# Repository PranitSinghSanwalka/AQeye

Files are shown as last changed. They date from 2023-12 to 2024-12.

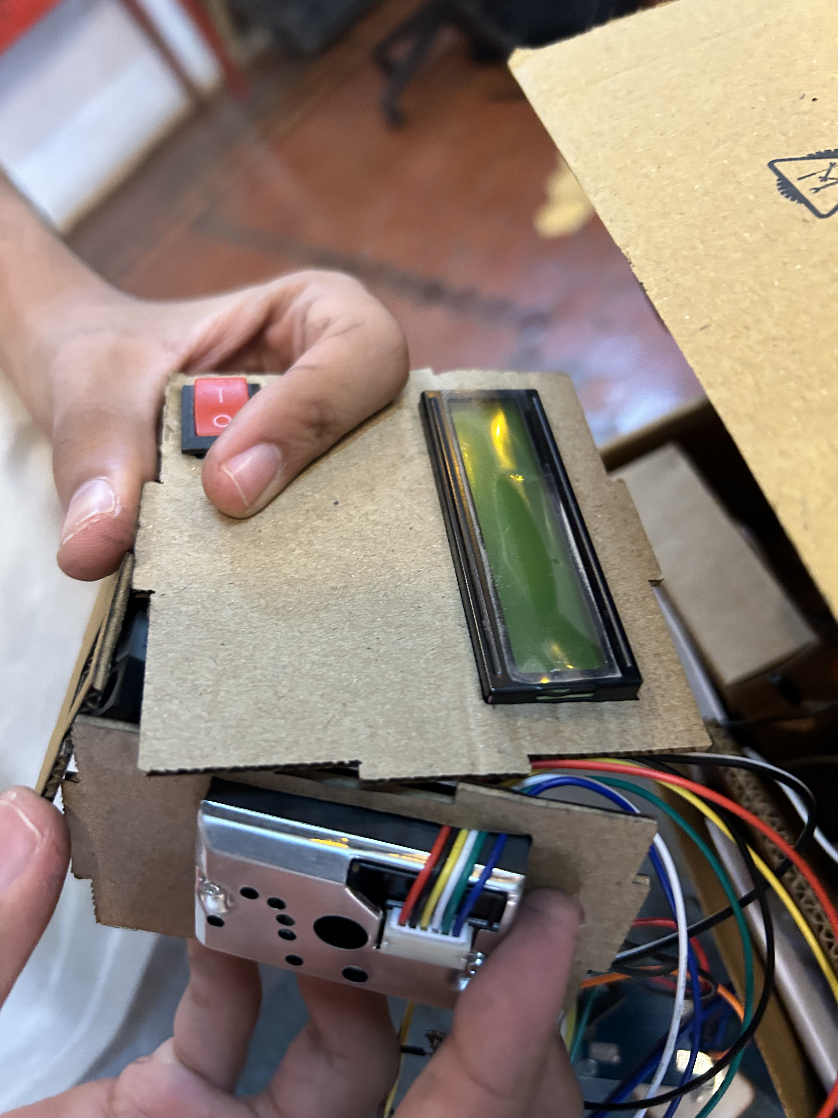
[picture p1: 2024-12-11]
FirstPrototype/Photos and Videos First Prototype/Full packaging paper prototype 2.jpeg

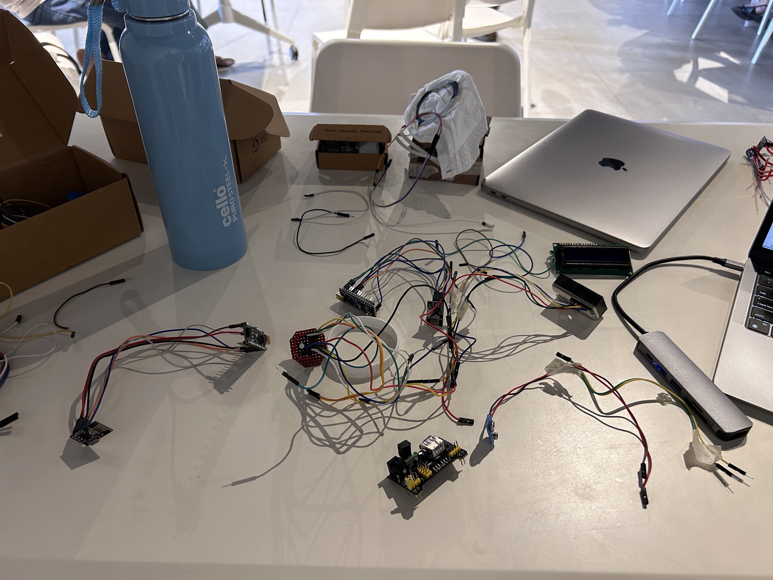
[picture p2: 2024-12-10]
Second Prototype/Second Prototype Photos and Videos/Testing_components_3.jpeg

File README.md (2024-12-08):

# AQeye
The AQeye Project by Pranit Sanwalka 

The goals:
Raise awareness about the growing air quality issues in growing cities, and try and get more people to wear masks to protect their bodies from harmful particles and air pollution

The Project:
A Mask that glows and changes colour, reacting to the air quality in real time via inbuilt air quality sensors, which also streans air quality data straight to your phone, so that you and those around you always know the air quality, and can take measures to protect themselves.

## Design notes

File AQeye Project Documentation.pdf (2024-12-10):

### AQeye

Problems:
1. Cities around the world, and especially in India, are getting increasingly polluted which poses a serious health risk
2. People in many of these cities, especially in Indian cities, are not aware of the need to wear masks to protect themselves from the pollution
3. People do not enjoy wearing masks, and do not know when they need to wear a mask and when not to, so they avoid wearing masks

Aims of Product
AQeye is a product aimed to increase awareness about the need to wear masks, and to give its users accurate on location data of the air quality in their immediate atmosphere, so that they know whether they need to wear a mask or not

Product:

AQeye is a mask that lights up and changes colour [LED’s change colour] depending on the air quality around you. This aims to send a message to those around you to wear a mask, through the use of stark colours.

AQeye also has sensors including a Dust Sensor, capable of measuring particles up to 0.3 microns small (smaller than PM2.5), and a CO2 gas sensor. It sends live data recorded from these sensors to your phone for you to check, and can alert you when you need to wear a mask based on this data.

Inspiration for product:
I had personally lived in the Delhi NCR region, one of the most polluted areas, for 4 years, and frequently visited it even during the highly polluted Diwalli and Winter times. While walking outside the Delhi airport, I nearly collapsed and fainted as I realised that I was unable to breathe, and couldnt walk for a long time, causing me to almost miss my flight. This incident made me wonder whether I could have protected my lungs and myself by wearing a mask in that situation, and made me wonder why I, and those around me, did not wear a mask. Thus I came up with AQeye to solve this.

The name AQeye is a spinoff of the term AQI (Air Quality Index) and was named with the idea that it allows the users to keep an “eye” on the Air Quality around them.

How it works:

The Product consists of two parts: The LED strip on the mask (The mask can be any disposable N95 mask and can be easily interchanged without needing a new LED system), and the main hub

First Prototype:

This prototype had the Dust Sensor, electronics and the batteries in a box shaped hub which could be attached to a backpack or other wearable via clips. This was connected to the LED’s on the mask by wire.

In the First prototype, I also attempted to collect Air Quality data from an online API with the help of a GPS sensor which returned latitude and longitude data, which the API took as an input to return data.

a. The idea was that the user would carry a small hub containing the main heavier or bulkier electronics and sensors, that could be attached to a pocket, bag or strapped to an arm or otherwise, and would allow the user to wear a mask wirelessly without the trouble of having an uncomfortable mask, as masks are already not favoured by many.
While intended to be wireless, with code and hardware already ready, we ran out of time and were unable to get the particular nRF24l01 transceivers to recognise each other, and there were no other transceivers immediately available.
i. Hub:
1. This is where the main electronics and sensors are stored
2. It should ideally be as small as possible, with the current electronics could possibly be reduced to the size of an uno card pack (maximum) Note: Currently it is much bigger as I have not used a single pcb board for the electronics, and most of the space is taken up by wiring, as the final prototype was assembled last minute without time to shorten connections, and readymade jumper cables were used.

### 3. It contains an esp wifi board, 7 pin LCD display (with I2C interface), A

breadboard power board, 2 9v batteries (one for the board, one for the other electronics, though with the right wiring one is enough), a dust sensor (Compact Optical Dust Particle Sensor GP2Y1010AU0F) (can sense down to pm2.5)
4. It was also intended to contain a GPS module and a radio transceiver module*
5. Current functionality: Senses the dust particle density in the air, and depending on this, controls the LED ring on the mask via cables. It also displays this data on a screen.
6. Intended functionality (could not be achieved, due to time constraints): Aside from the dust sensor, the esp would also use data from an API which returns AQI values from the nearest meteorological data center, as fitting an “AQI” sensor is unrealistic, as it depends on too many factors, while dust and particulate matter not only is damaging, but varies more from place to place, and can be filtered out by an n95/n99 mask (most).
The board would thus use this data to calculate the colour the mask should reflect, and then using the transceiver sends data to the mask
ii. Mask:
1. A disposable n95 mask (for the project the disposable 3M Vflex mask was used due to its spilloff areas on the sides, which provided more space to mount electronics if needed (though not used), and has a flat bottom, so an led ring can be easily stuck

2. This mask currently has an led ring that is attached to the mask (Was intended to be an LED strip, but a ring consumes less power and proved to be more reliable and easier to interface)
3. It was intended to have an arduino nano (or smaller board) attached to a transceiver and then this LED ring, allowing for wireless transmission between the hub and mask to ensure the mask is as light as possible.
2. Planned features (Aside from some of the main intended features of the first prototype mentioned above)
a. A notification feature that notifies users on their phone when the air quality of a certain area that they are in exceeds a certain amount
b. A “forecast” feature that would allow users to tell whether they need to take their mask in the morning, by checking the color it is glowing
The idea behind this was that many people hang their masks on their front door or near their exit (used to during covid) for easy access, and this could provide a visual aide as to whether the air quality outside (according to API data) is good or bad, like a rain forecast
c. A map integrated feature that allows you to look at places that you visited and their corresponding air quality near you (from recorded data when you visited, to help you plan ahead.
3. Some other constraints:
a. The api feature would need a permanently on hotspot, which may not be ideal, but could work for the home forecast feature
b. Scaling down the hub and making it more robust and user friendly is always an issue

Problems faced:

Initially, a wireless connection was planned between the LED’s on the mask and the main hub using NRF24L01 Radio transceivers, and an additional arduino board and battery separately on the mask to allow this, however a connection could not be reliably established, after several tries and different boards.

Additionally, the hub was large and difficult to carry around, even though most of the volume inside the hub was occupied by jumper cables that could be eliminated via the use of a PCB.

There was also the safety concern of having batteries on the users face if a wireless connection was to be used, which was not ideal.

Finally, an LED ring was used instead of an LED strip as the LED strips that had been purchased stopped working, and due to the time constraints of the Maker’s Asylum Innovation School Program where this was developed, an LED ring that was immediately available was used as an alternative.

More information on the first prototype can be found here:

The second prototype:

Video (Presenting working prototype at Make, Break, Create Summit, Museum of Solutions, Mumbai in partnership with the UNDP): https://www.instagram.com/reel/C6Vq0jooUJX/?utm_source=ig_web_button_share_sheet&igsh=MzRlODBiNWFlZA== (https://www.instagram.com/reel/C6Vq0jooUJX/?igsh=MzRlODBiNWFlZA==)

To create a disposable n95 mask attachment that reacts to the air quality around it in real-time, and reflects it by glowing different colors. Real-time data of air pollution measurements/values in their immediate environment also need to be sent to the user's phone so that they know when to wear a mask and when they are safe or not

The second prototype built on the first, but abandoned the wireless transmission due to the lack of reliability and safety concerns of batteries on the face.

Description:
The second AQeye prototype consists of a mask with an LED strip, similar to the one in the first prototype, which is connected by a short wire to a neckband which the user can wear around their neck comfortably. This runs on rechargeable battery power. It boasts a Dust Sensor and a gas sensor capable of detecting CO2 concentrations, with Data sent directly to the user's phone.

The mask displays 3 colours: Green (Good), Yellow (Poor) and Red (Extremely Injurius).

Design of the second prototype:

The hub was also redesigned to become a neckband, which connects to the LED’s on the mask via a short wire, which increases the comfort of carrying it around, and also allows the mask and hub to become one unit. A neckband may also be more socially acceptable due to the wide variety of electronics filled neckbands on the market, such as those with bluetooth earphones and the Bose Soundwear Companion Wireless Wearable Speaker, which inspired the product's design.

The screen to display the air quality, which was included in the initial prototype, was abandoned as a screen would not be easy to view on a neckband, and sending data to a phone not only saves space, but also allows more information to be displayed due to a larger screen. It also reduces the volume and weight.

Finally, the Air Quality API that was planned to be used in the first prototype was abandoned, as later it came to light that it would not be as useful as having on location data. Additionally the API data is offered to everyone directly on their phones, therefore the AQeye mask would not be helping the user much by giving them data they already had access to.

Problems Faced:
- The second prototype's neckband design was rushed, resulting in a large bulky neckband with open spaces to allow modification of the electronics due to time constraints.
- Additionally, Wifi was used as a means to transmit data from the neckband to the user’s phone [Blynk App] as this was the easiest and fastest way to achieve this goal in the short time period of the Maker’s Asylum SDG Acceleration Program where it was improved upon. In a future model, bluetooth will be used for transmission. However a custom app will have to be created.
- (The ESP32 board used has built in BT capabilities)
- A latch system needs to be designed for the LED’s on the mask so that the mask can be easily changed
- A higher capacity battery probably needs to be used, and an operating voltage optimal for all components set, preferably without a buck converter as it consumes a lot of power.
- Finally, the product has to be made more aesthetically pleasing, comfortable, compact and lightweight so that it appeals to users. This can be achieved to some extent through:
- Using a singular custom Flex PCB shaped to the neckband’s size. This will make it more compact and robust
- The neckband itself can be 3d printed and be fully enclosed to make it more aesthetically pleasing, compact and comfortable

Components used:

- 1x ESP32 (Main Board)
- 1x Lm2596 DC Buck Converter Step Down Power Module
- 2x 3.3V 600mAh LiPo Batteries (Wired in series to give 7.6V to the buck converter)
- 1x WS2812B LED Strip (12 LED’s) / NeoPixel LED Strip
- 1x Sharp GP2Y1010AU0F Optical Dust Sensor
- 1x MQ-135 Gas Sensor

Ideas for improvements:
a. A notification feature that notifies users on their phone when the air quality of a certain area they are in exceeds a certain amount
b. A “forecast” feature that would allow users to tell whether they need to take their mask in the morning, by checking the color it is glowing
The idea behind this was that many people hang their masks on their front door or near their exit (used during COVID) for easy access, and this could provide a visual aide as to whether the air quality outside (according to API data) is good or bad, like a rain forecast
c. A map-integrated feature that allows you to look at places that you visited and their corresponding air quality near you (from recorded data when you visited, to help you plan.

Sketches, diagrams and images of the prototypes:

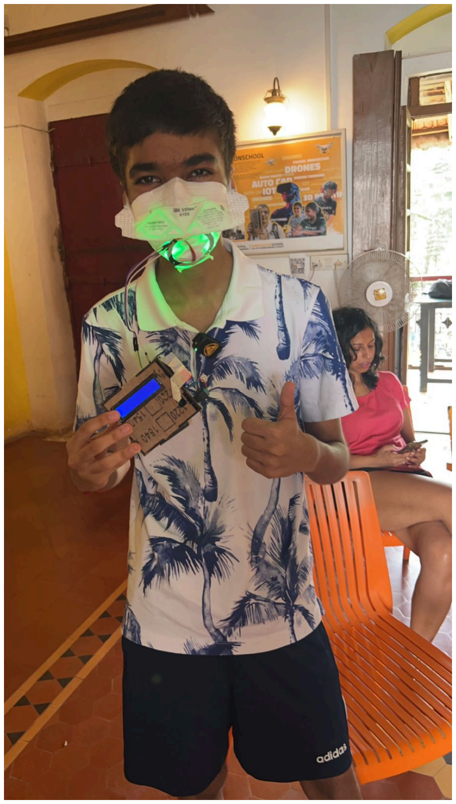
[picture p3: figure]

Picture of the first prototype (Extremely rough version, led ring not properly attached, hub made out of thin plywood hot glued together and batteries taped on.)

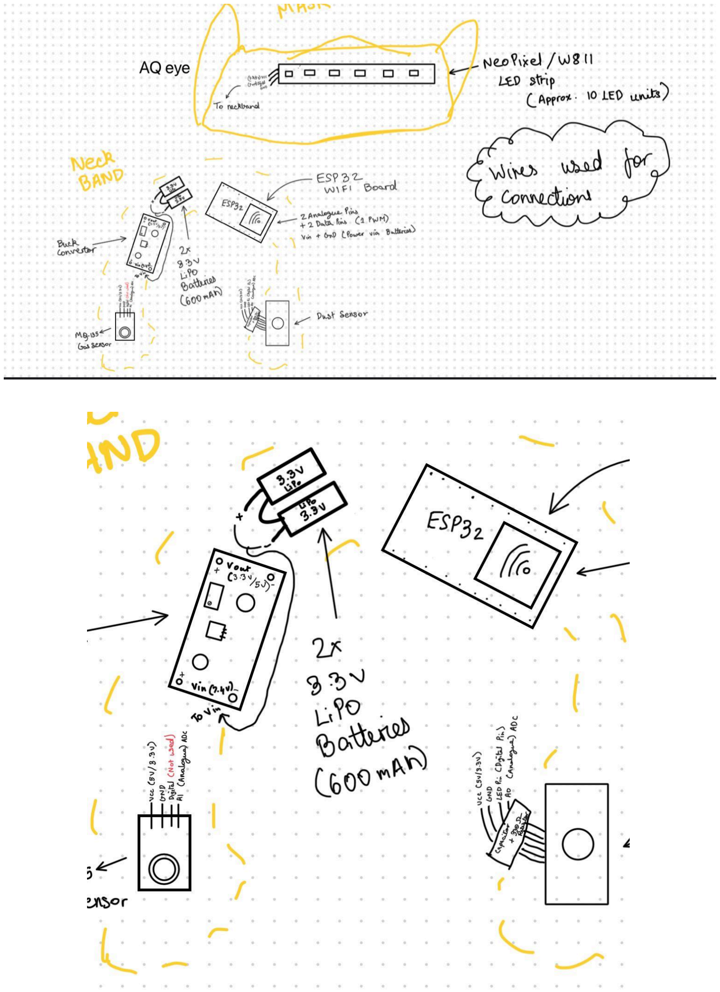
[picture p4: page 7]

Note: the voltage requirements of the ESP32 (3.3V) is lower than the operating voltage of the sensors (5V) and LEDs which was not accounted for.

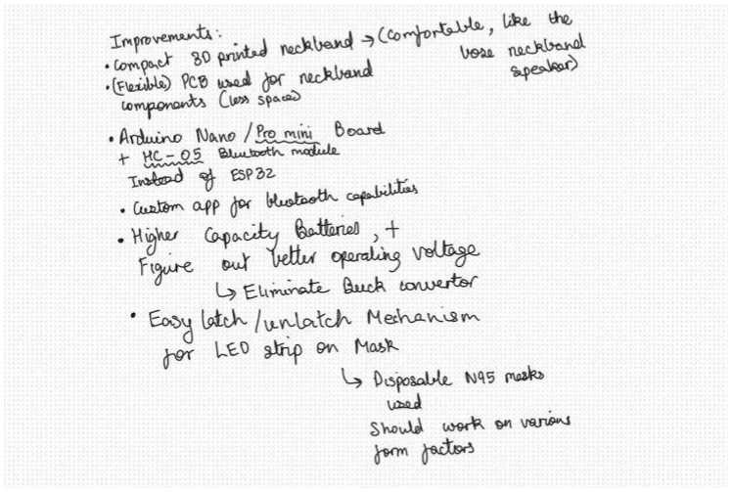
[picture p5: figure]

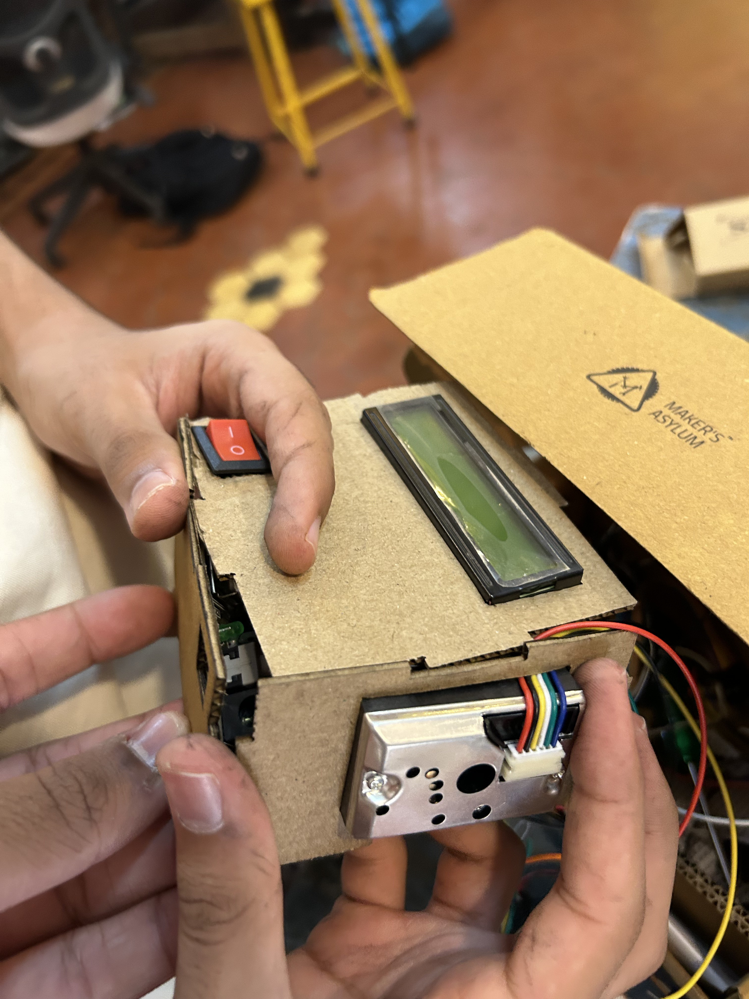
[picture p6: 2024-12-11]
FirstPrototype/Photos and Videos First Prototype/Full packaging paper prototype 3.jpeg

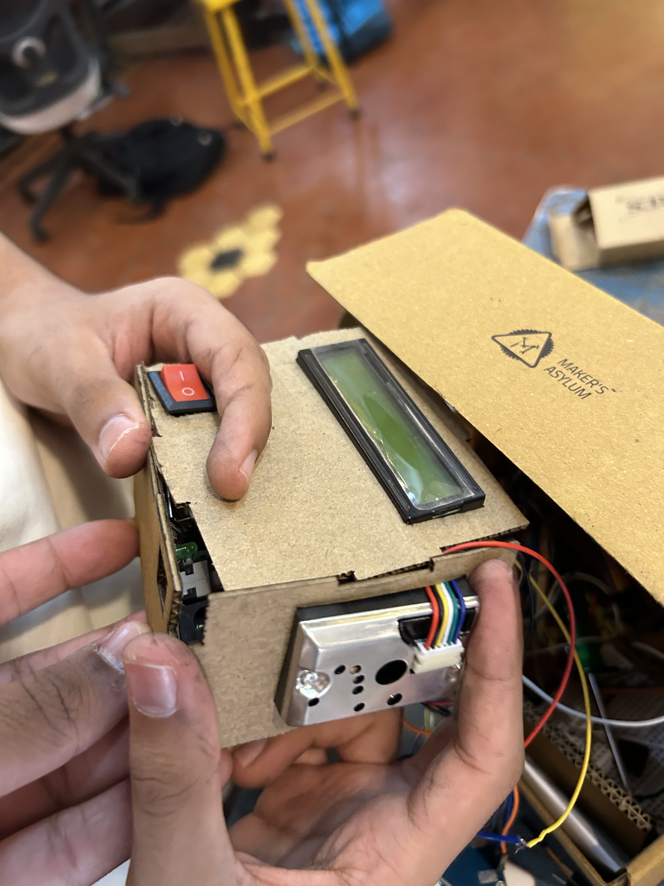
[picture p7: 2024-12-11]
FirstPrototype/Photos and Videos First Prototype/Full packaging paper prototype 4.jpeg

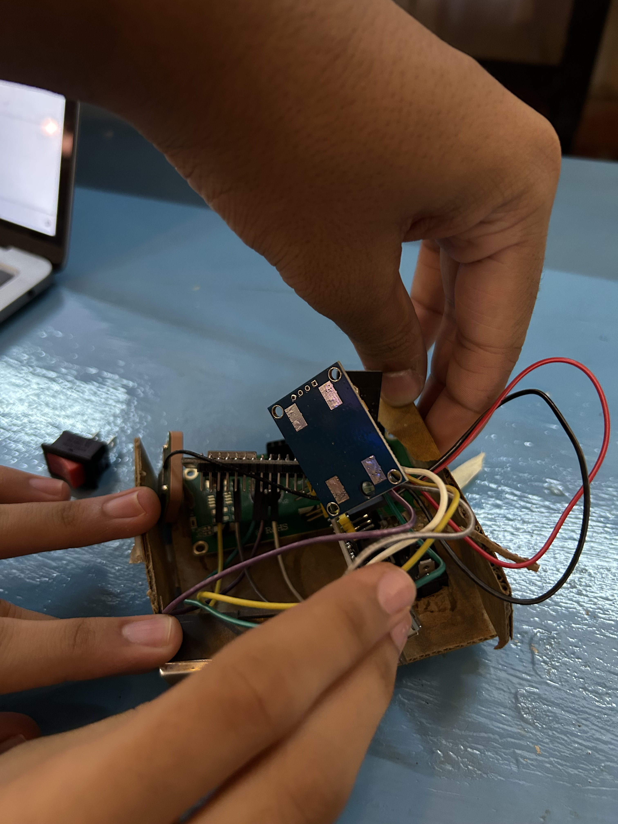
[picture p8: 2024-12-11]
FirstPrototype/Photos and Videos First Prototype/Paper_Prototype_3.jpeg

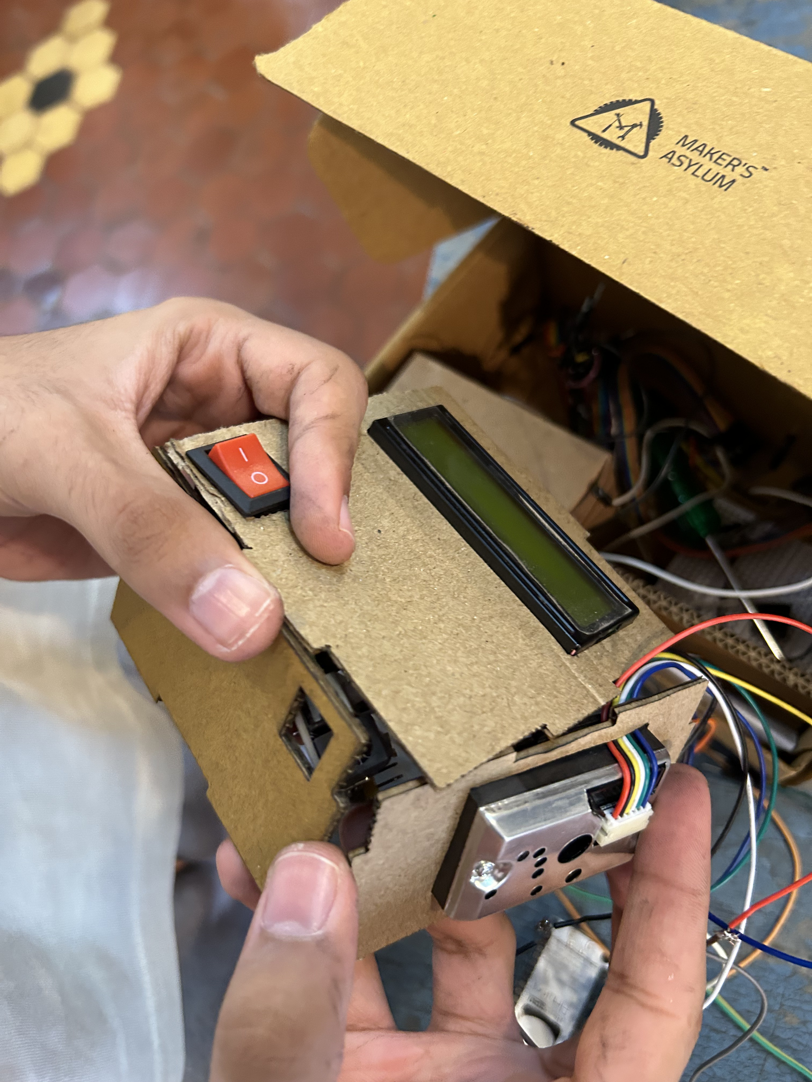
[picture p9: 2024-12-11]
FirstPrototype/Photos and Videos First Prototype/Full packaging paper prototype.jpeg

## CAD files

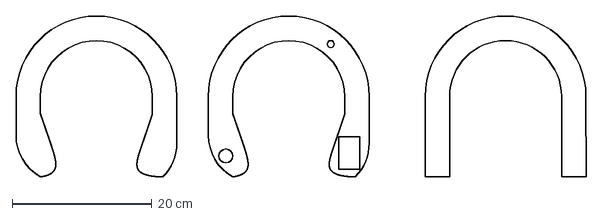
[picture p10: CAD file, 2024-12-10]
Second Prototype/Second Prototype CAD files/AQeye Headband v6.dxf
81.5 x 23.0 cm

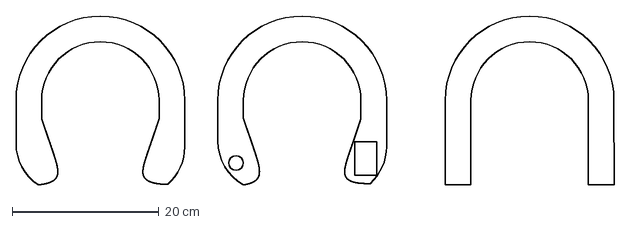
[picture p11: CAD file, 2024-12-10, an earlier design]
Second Prototype/Second Prototype CAD files/AQeye Headband v5.dxf
81.5 x 23.0 cm

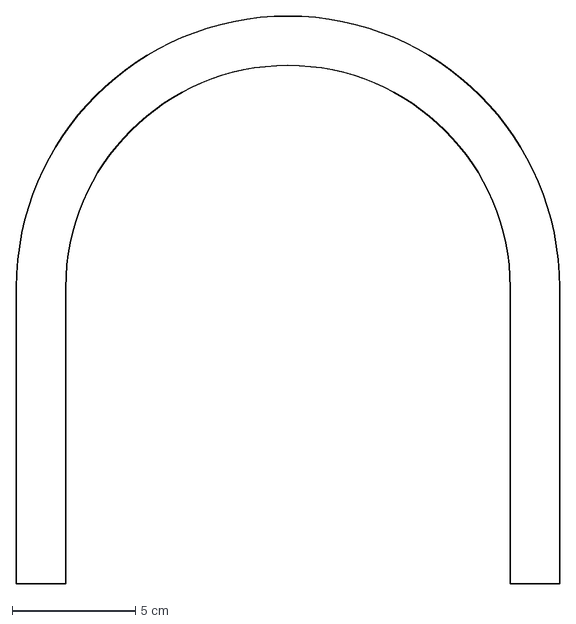
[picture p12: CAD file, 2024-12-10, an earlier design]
Second Prototype/Second Prototype CAD files/AQeye Headband v1.dxf
22.0 x 23.0 cm

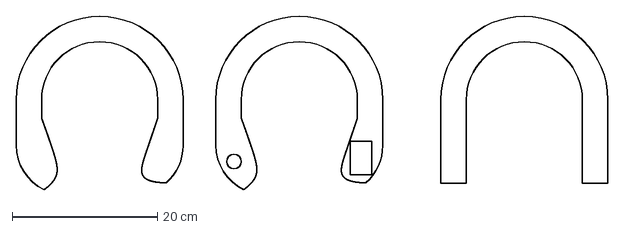
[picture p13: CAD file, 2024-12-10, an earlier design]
Second Prototype/Second Prototype CAD files/AQeye Headband v3.dxf
81.5 x 23.9 cm

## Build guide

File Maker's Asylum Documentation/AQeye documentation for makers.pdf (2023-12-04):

## AQeye

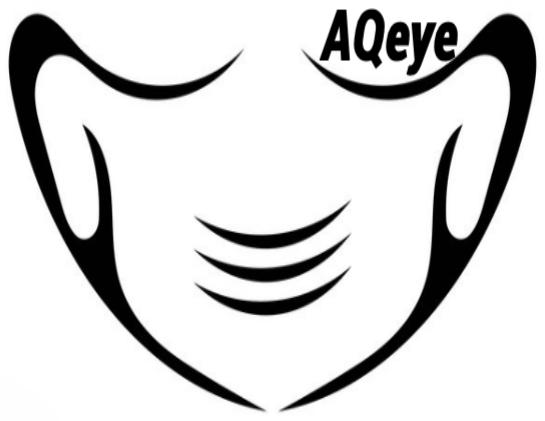
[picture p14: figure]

### 1. Idea

There is a serious risk to public health as India deals with a significant worsening of Air Quality, especially in its major cities, for example, its capital city of Delhi, where every winter the AQI index rises far above 300 due to a variety of reasons. We are pleased to present AQeye, a ground-breaking solution created to increase awareness in response to this urgent need. AQeye responds to the Air Quality around it in real time by dynamically changing colour, thus indicating to the user, and people around the user, the desperate nature. This cutting-edge feature is a potent tool for involving people and communities, encouraging a shared commitment to reduce air pollution and give respiratory health first priority, along with increasing awareness about the issue.

### 2. Problem Statement

There is an urgent environmental crisis in India due to the rising Air Quality Index (AQI) values, which are having a negative impact on people's health and well-being. Growing pollution from transportation, industry, and other sources is a serious concern that has to be addressed right away in order to stop this worrying trend. As a revolutionary answer to this pressing problem, AQeye is our ground-breaking invention, as we need to find a way to increase the awareness of the worsening air quality, and the dire need to wear masks that this creates.

### 3. SDG in play

SDG-3

### 4. Constraints

- The device had to be waterproof. All circuitries should be enclosed.
- It had to be portable, light and comfortable to carry around and use
- It had to be sturdy and durable, to withstand daily use
- It should be aesthetically appealing as an ugly circuit is not appreciated.
- The mask should be more comfortable.
- The box should be made more portable and lightweight

### 5. Solutions Brainstorming

We had many ideas starting this project off something which can purify the air but since we were on a time constraint we decided not to do that and instead work on something else. We started brainstorming and thought why not make a project which can help create awareness about the increasing air quality levels in India. Thats how the idea of ‘AQeye” was born.We decided to have all our electronics in a box which can be clipped onto anything such as your backpack.It has a transceiver which sends data to an arduino which is attached onto the mask. To show increasing AQI we decided to add a LED strip which can change colours on the mask as per the air quality.Moreover,we have very exciting ideas for the future such as adding an bluetooth module which will send a notification to the users phone and help the user understand when to wear a mask and when not to.We also plan to add a humidifier inside the mask in the near future and also have a technology which will light up the mask when it senses the AQI is going be increasing that particular day, thus telling the user in the morning whether they need to wear the mask that day.

### 6. Final Solution

- Name of the project
AQeye
Instead of the “I” in AQI we replaced it with eye since we are trying to spread awareness about the increasing air quality levels.

·Design process

Our design idea constitutes of a mask, with leds fixed at the bottom, shooting upwards to create an aesthetic “glow” and allow the light to spread without it being uncomfortable for the user. The mask will have a small board and transceiver attached to the bands to control the colours. Additionally, there will be a box, roughly 5 by 3cm, which will have a screen to display the readings, and an on off button. We aimed to make the box and packaging as small as possible to make it comfortable for the user.

·Materials and machines used Materials

- 1x BREADBOARD
- JUMPER WIRES
- 1x ARDUINO NANO
- 1x ESP8266
- 1x 3M 9105 VFLEX N95
- 1 METERx WS2812B LED STRIP
- 1x ELECTRONIC SPICES 9V BATTERY AND CONNECTOR
- 1x I2C LCD(16x2)
- 2x REES52 NRF2 NRF24LO1 2.4GHZ WIRELESS Transcievers
- 1x NEO-6M GPS MODULE
- 2x NRF24L01 Wireless transceivers
- 2x 9V batteries
- 2x 9V battery connectors
- GP2Y1010AU0F Optical Dust and PM2.5 Sensor Module
- MB102 breadboard power supply module

TOOLS

- WIRE CLIPPERS
- SCISSORS
- Tape
MACHINES
- LASER CUTTING
- 3D PRINTING MACHINE
- SOLDER IRON

SKILLS USED
IOT
Electronics
Cad
Lazer Cutting

CHALLENGES FACED AND SOLUTIONS

The first issue we ran into was finding a mask on which LED’s could be comfortably attached, with a great enough surface area, and enough volume to ensure that the users comfort was not compromised. We thus settled on the 3M Vflex disposable respirator, due to its large surface area, and comfortable boxy nature. The flaps on the sides also gave us room to attach electronics if we needed to without compromising on integrity of the mask
While initially we wanted to add the functionality of bluetooth to allow the user to get notifications on their phone, we were unable to do so due to time constraints, so we decided to build on that in a later prototype.
A second issue we ran into, was that our GPS sensor started malfunctioning, thus we had to push the API usage to a later prototype, when we could get it to work, as our API to get the AQI depended on the user’s latitude and longitude, which we needed a GPS sensor for Another issue that we ran into was that our Dust and PM2.5 sensor was not perfectly calibrated, so we decided we used an existing prototype at the maker space, which had a hepa filter and an air outlet, to create a dustless environment to simulate ‘0’ mg/m^3 to calibrate the dust sensor. Finally while we planned to use two NRF24L01 Wireless transceiver modules to make communication between the Mask and the Hub wireless, we were unable to get the transceivers to work between an Arduino nano and ESP8266, so we ended up drilling a hole in our prototype box, and using jumper cables to make an extended wire through the hole to allow us to wire the LED’s on the Mask directly to the Hub to make up for a lack of wireless transmission

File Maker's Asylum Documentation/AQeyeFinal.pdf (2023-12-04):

Problem
Our core cities in India specifically, but also all around the world are getting very polluted, and people need to know when they need to wear masks. Additionally, we want to spread awareness about the issue of pollution and the vitality of wearing masks.

Idea:
Create a mask that reacts to the pollution in the air, and lights up different colours (Green if normal, Orange/yellow, Red if extremely polluted)

Our Aim:
Create a mask with leds, and a main hub which can be clipped to a bag. This hub should have sensors to measure air quality, a screen to display this, and should be able to wirelessly transmit this exact data up to the mask.

Block diagram based on objectives
Create a block diagram based on the objectives

HUB:
Should be as small as possible

The mask:

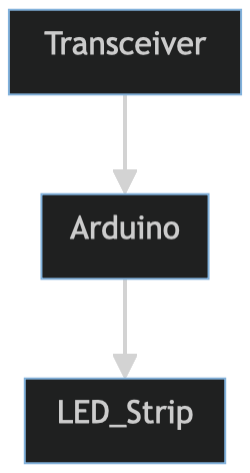
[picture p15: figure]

Code Objective:

HUB
Take input from from the GPS sensor Input in API
Get AQI Values
Get AQI Values from sensor
Display on LCD screen
Decide which colour to display, based on range Send value to the mask via transceiver

Mask:
Get values from transceiver
Control LEDs on mask to display colours

Parts (General)

Transceivers:
REES52 NRF2 nRF24L01 2.4GHz Wireless Transceiver x2 For transmission between phone and clip:
HC-05 Bluetooth receiver

For AQI
Adafruit SGP40 Air Quality Sensor/SeedStudio Grove Air quality sensor v1.3

Arduino Nano (For the main receiver)
ESP8266

GPS sensor

LCD display (Silicon TechnoLabs LCD 16x2 Alphanumeric Display BJHD162A)

LED strip

Switches (on/off) (1 switch for the main hub, one button for the mask)

Battery 9V

buzzer(5V Active Electromagnetic Buzzer)

clip(NSSP 41 mm Black Large Paper Clips)

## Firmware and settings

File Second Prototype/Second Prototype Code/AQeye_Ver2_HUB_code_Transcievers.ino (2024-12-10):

//Code with transcievers for the main HUB (Not used in second prototype, explained in documentation)

//Dust Sensor
//MQ-135
//TRANSCIEVERS
//LED
//BUTTON
//BUZZER
//Screen


#include <LiquidCrystal_I2C.h>
#include <RH_NRF24.h>
#include "MQ135.h"
#define ANALOGPIN A2    //  Define Analog PIN on Arduino Board
#define RZERO 206.85    //  Define RZERO Calibration Value
MQ135 gasSensor = MQ135(ANALOGPIN);
 
//TRANSCIEVER
// RH_NRF24 nrf24(8, 7); 
 
// uint8_t color;
//</>


/* Code for the main hub with the GP2Y1010AU0F dust sensor and MQ-135 sensor with wireless radio transmission */


//Code by Pranit Sanwalka


//only LED TEMP
// #include <FastLED.h>
// #define DATA_PIN 15
// #define NUM_LEDS 20

// #define COLOR_ORDER GRB

// CRGB leds[NUM_LEDS];
// int clr = 1;

// int led_num = 15;
//TEMP END

LiquidCrystal_I2C lcd(0x27, 16, 2); //set lcd adress for 16 by 2

//Dust Sensor
int measurePin = A0; //Connect dust sensor to Arduino A0 pin
int ledPower = 14;   //Connect led pin

int samplingTime = 280;
int deltaTime = 40;
int sleepTime = 9680;

float voMeasured = 0;
float calcVoltage = 0;
float dustDensity = 0;
int clrIndicator = 1;
int threshold1 = 100;
int threshold2 = 300;

//Dust Sensor

//MQ
int sensorValue;
int digitalValue;
//MQ


/*
  Button

  Turns on and off a light emitting diode(LED) connected to digital pin 13,
  when pressing a pushbutton attached to pin 2.

  The circuit:
  - LED attached from pin 13 to ground through 220 ohm resistor
  - pushbutton attached to pin 2 from +5V
  - 10K resistor attached to pin 2 from ground

*/

// constants won't change. They're used here to set pin numbers:
const int buttonPin = 2;  // the number of the pushbutton pin
const int buzzerpin = ;

// variables will change:
int buttonState = 0;  // variable for reading the pushbutton status

void setup(){
  Serial.begin(115200);
  pinMode(2, INPUT);
  //Other

  pinMode(ledPower,OUTPUT);
  lcd.init();
  lcd.clear();
  lcd.backlight();

  //button
  pinMode(buzz)
  // initialize the pushbutton pin as an input:
  pinMode(buttonPin, INPUT);



  //transmitting
  int color=1;
  while (!Serial)
    ; // wait for serial port to connect. Needed for Leonardo only
  if (!nrf24.init()) 
  {
    Serial.println("init failed");
 
  }
  // Defaults after init are 2.402 GHz (channel 2), 2Mbps, 0dBm
  if (!nrf24.setChannel(3)) 
  {
    Serial.println("setChannel failed");
  }
  if (!nrf24.setRF(RH_NRF24::DataRate2Mbps, RH_NRF24::TransmitPower0dBm)) {
    Serial.println("setRF failed");
  }
  Serial.println("Transmitter started");

  //gas sensor
  float rzero = gasSensor.getRZero();
  delay(3000);
  Serial.print("MQ135 RZERO Calibration Value : ");
  Serial.println(rzero);
  //gas sensor


  // //TEMP
  // FastLED.addLeds<WS2811, DATA_PIN, GRB>(leds, NUM_LEDS);
  // //TEMPEND
}

void loop(){


  //dust sensor
  digitalWrite(ledPower,LOW); // power on the LED
  delayMicroseconds(samplingTime);

  voMeasured = analogRead(measurePin); // read the dust value

  delayMicroseconds(deltaTime);
  digitalWrite(ledPower,HIGH); 
  delayMicroseconds(sleepTime);

  // 0 - 5V mapped to 0 - 1023 integer values
  // recover voltage
  calcVoltage = voMeasured * (5.0 / 1024.0);

  // linear eqaution taken from http://www.howmuchsnow.com/arduino/airquality/
  dustDensity = 170 * calcVoltage - 0.1;

  //dust sensor end
  float ppm = gasSensor.getPPM();
  delay(1000);
  Serial.print("CO2 ppm value : ");
  Serial.println(ppm);
  lcd.setCursor(0,0);
  lcd.print("   Tech Maker   ");
  lcd.setCursor(0,1);
  lcd.print("CO2 : ");
  lcd.print(ppm);
  lcd.print("PPM");


  //
  Serial.println("Dust/PM2.5 density: " + String(dustDensity) + "ug/m3"); // unit: ug/m3
  lcd.setCursor(1,0);
  lcd.print(String(dustDensity));
  float ppm = gasSensor.getPPM();
  delay(1000);
  Serial.print("CO2 ppm value : ");
  Serial.println(ppm);
  lcd.setCursor(1,1);
  lcd.setCursor(0,1);
  lcd.print("CO2 : ");
  lcd.print(ppm);
  lcd.print("PPM");
  //Colors
  if(dustDensity<threshold1) {    //with aqi, will be: if (dustDensity<threshold)&&(AQI<aqiThreshold)
    Serial.print("Green");
    lcd.setCursor(6,1);
    lcd.print("Green");
    clrIndicator = 1;
  } else if(dustDensity > threshold1 && dustDensity < threshold2) {
    Serial.print("Yellow");
    lcd.setCursor(6,1);
    lcd.print("Yellow");
    clrIndicator = 2;
  } else {
    Serial.print("Red");
    lcd.setCursor(6,1);
    lcd.print("Red");
    clrIndicator = 3;
  }
  // transmitinfo(clrIndicator);

  if clrIndicator = 3 {
    buzzer();
  }
  Serial.println(clrIndicator);
  changecolor(clrIndicator);
  delay(1000);
}

//BUZZER
void buzzer() {
  int pressed = 0
  while (pressed != 1) {
    pinMode(buzzer, HIGH);
      // read the state of the pushbutton value:
    buttonState = digitalRead(buttonPin);

    // check if the pushbutton is pressed. If it is, the buttonState is HIGH:
    if (buttonState == HIGH) {
      // turn LED on:
      digitalWrite(buzzerpin, LOW;
      pressed = 1
    }
  }
}

//Transmit Data

// void transmitinfo(int data){
//   Serial.println("Sending to gateway");
//   uint8_t data[2];
//   data[0] = color;
  
//   Serial.println("------------- Measurements -------------");
//   Serial.print("Color: ");
//   Serial.print(data[0]);
//   nrf24.send(data, sizeof(data));
//   nrf24.waitPacketSent();
  
//   // Now wait for a reply
//   uint8_t buf[RH_NRF24_MAX_MESSAGE_LEN];
//   uint8_t len = sizeof(buf);
 
//   if (nrf24.waitAvailableTimeout(1000))
//   {
//     // Should be a reply message for us now
//     if (nrf24.recv(buf, &len))
//     {
     
//       Serial.print("got reply: ");
//       Serial.println((char*)buf);
//     }
//     else
//     {
     
//       Serial.println("recv failed");
//     }
//   }
//   else
//   {
//     Serial.println("No reply.");
    
//   }
//   delay(5000);
// }



//TEMP
// void changecolor(int clr){
//   if (clr == 1) {
    
//     for(int i = 1; i <= led_num; i++) {
//       leds[i] = CRGB(0,255,0);
//     }
//     FastLED.show();
//     delay(100);
//   } else if(clr == 2) {
//     for(int i = 1; i <= led_num; i++) {
//       leds[i] = CRGB(255,255,0);
//     }
//     FastLED.show();
//     delay(100);
//   } else if(clr==3) {
//     for(int i = 1; i <= led_num; i++) {
//       leds[i] = CRGB(255,0,0);
//     }
//     FastLED.show();
//     delay(100);
//   } else {
//     Serial.println("Error");
//   }
//   FastLED.show();
// }
// //END temp

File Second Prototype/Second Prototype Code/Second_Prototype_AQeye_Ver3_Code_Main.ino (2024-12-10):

//Final Second Prototype code used
//Incluldes 2 sensors and use of Blynk to display

//Code by Pranit Sanwalka

//blynk
#define BLYNK_PRINT Serial
#define BLYNK_TEMPLATE_ID "TMPL3MgeYrEXM"
#define BLYNK_TEMPLATE_NAME "AQeye"
#define BLYNK_AUTH_TOKEN "NoYlgHENX-VrE7IopVXNi0sxN6NnTXj8"

//Wifi
#include <WiFi.h>
#include <WiFiClient.h>
#include <BlynkSimpleEsp32.h>


const char* ssid = "Your SSID";
const char* password = "Password";


#include <FastLED.h>
#define DATA_PIN 5
#define NUM_LEDS 20
#include "MQ135.h"
#define ANALOGPIN 36  //  Define Analog PIN on Arduino Board
#define RZERO 265     //  Define RZERO Calibration Value
MQ135 gasSensor = MQ135(ANALOGPIN);

#define COLOR_ORDER GRB

CRGB leds[NUM_LEDS];
int led_num = 18;
int clrIndicator = 1;
int threshold1 = 100;
int threshold2 = 300;
const int gthreshold1 = 100;
const int gthreshold2 = 200;

void setup() {

  Serial.begin(115200);
  delay(1000);
  FastLED.addLeds<WS2811, DATA_PIN, GRB>(leds, NUM_LEDS);
  delay(1000);
  FastLED.show();
  WiFi.begin(ssid, password);
  Serial.println("\nConnecting");
  for (int i = 1; i <= led_num; i++) {
    leds[i] = CRGB(0, 0, 255);
  }
  FastLED.show();
  while (WiFi.status() != WL_CONNECTED) {
    Serial.print(".");
    delay(100);
  }

  Blynk.begin(BLYNK_AUTH_TOKEN, ssid, password);

  Serial.println("\nConnected to the WiFi network");
  for (int i = 1; i <= led_num; i++) {
    leds[i] = CRGB(0, 255, 0);
  }

  Serial.print("Local ESP32 IP: ");
  Serial.println(WiFi.localIP());


  float rzero = gasSensor.getRZero();
  delay(3000);
  Serial.print("MQ135 RZERO Calibration Value : ");
  Serial.println(rzero);
}

void loop() {
  int dustDensity = random(1, 10) + 200;

  Serial.println("Dust/PM2.5 density: " + String(dustDensity) + "ug/m3");  // unit: ug/m3
  Serial.println(String(dustDensity));


  float ppm = gasSensor.getPPM();
  delay(1000);
  Serial.print("CO2 ppm value : ");
  Serial.println(ppm);

  Blynk.virtualWrite(V0, dustDensity);
  Blynk.virtualWrite(V1, sppm);



  if (dustDensity < threshold1) {  //with aqi, will be: if (dustDensity<threshold)&&(AQI<aqiThreshold)
    Serial.println("Green");
    clrIndicator = 1;
  } else if (ppm < gthreshold1) {
    Serial.println("Green");
    clrIndicator = 2;
  } else if (dustDensity > threshold1 && dustDensity < threshold2) {
    Serial.println("Yellow");
    clrIndicator = 2;
  } else if (ppm > gthreshold1 && ppm < gthreshold2) {
    Serial.println("Yellow");
    clrIndicator = 2;
  } else if (dustDensity > threshold2) {
    Serial.println("Red");
    clrIndicator = 3;
  } else if (ppm > gthreshold2) {
    Serial.println("Red");
    clrIndicator = 3;
  } else {
    Serial.println("Error");
    clrIndicator = 1;
  }
  Serial.println(clrIndicator);
  changecolor(clrIndicator);
  delay(5000);
}


void changecolor(int clr) {
  if (clr == 1) {

    for (int i = 1; i <= led_num; i++) {
      leds[i] = CRGB(0, 255, 0);
    }
    FastLED.show();
    delay(100);
  } else if (clr == 2) {
    for (int i = 1; i <= led_num; i++) {
      leds[i] = CRGB(255, 255, 0);
    }
    FastLED.show();
    delay(100);
  } else if (clr == 3) {
    for (int i = 1; i <= led_num; i++) {
      leds[i] = CRGB(255, 0, 0);
    }
    FastLED.show();
    delay(100);
  } else {
    Serial.println("Error");
  }
  FastLED.show();
}

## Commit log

2024-12-10 Adding Second Prototype Files
    [AQeye Headband v1.dxf, AQeye Headband v2.dxf, AQeye Headband v3.dxf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]
2024-12-10 Re-adding first prototype files
